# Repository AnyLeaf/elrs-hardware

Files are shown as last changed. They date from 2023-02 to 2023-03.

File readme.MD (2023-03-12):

# AnyLeaf ELRS 2.4Ghz diversity Rx hardware

This repo contains published hardware information for the AnyLeaf ELRS receivers.
It contains schematics, KiCad schematic and PCB layout files, and production files
(Gerbers, drill files, bill of materials (BOM), and pick+place files). If you have any questions
or concerns, please post a Github issue here, or contact us at [anyleaf@anyleaf.org](mailto:anyleaf@anyleaf.org).

## This repo contains 2 designs:
- Single radio (SX1280), with ESP8285 MCU, and SkyWorks SE2431 LNA/PA/antenna mux.
- Dual radio (SX1280), with ESP32-PICO-V3 MCU, and SkyWorks RFX2401C LNA/PAs.

Images of the schematics are provided as PNG files in the main repo; this is the easiest
way to view the schematics.

To view details, including PCB layouts, open the schematic and/or PCB files in 
[KiCad](https://www.kicad.org/).

For info on specific parts chosen, including part numbers at Digikey and LCSC, open
the schematic files in KiCad, and examine part properties.

All parts are on the same side of the PCB. Resistors and capacitors are *0402* size.

## [ExpressLRS home page](https://www.expresslrs.org/3.0/)

## [ExpressLRS hardware repo](https://github.com/ExpressLRS/ExpressLRS-Hardware)

## [AnyLeaf single-radio 2.4Ghz receiver](https://www.anyleaf.org/elrs-rx)

## [AnyLeaf dual-radio 2.4Ghz receiver](https://www.anyleaf.org/elrs-rx-dualradio)

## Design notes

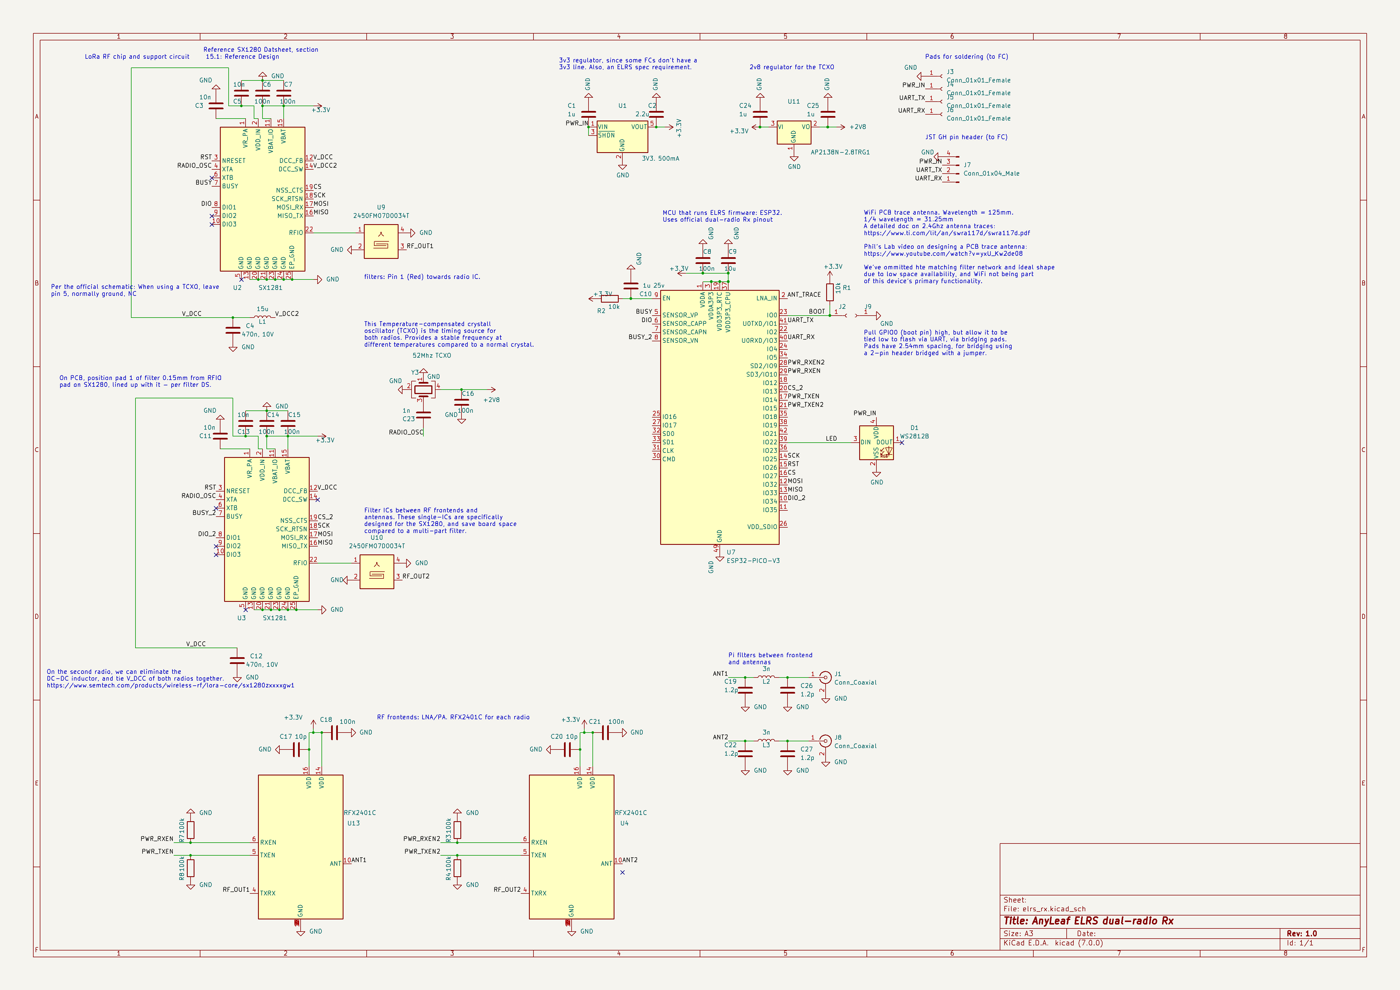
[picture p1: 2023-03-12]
dual radio 2.4Ghz schematic.png

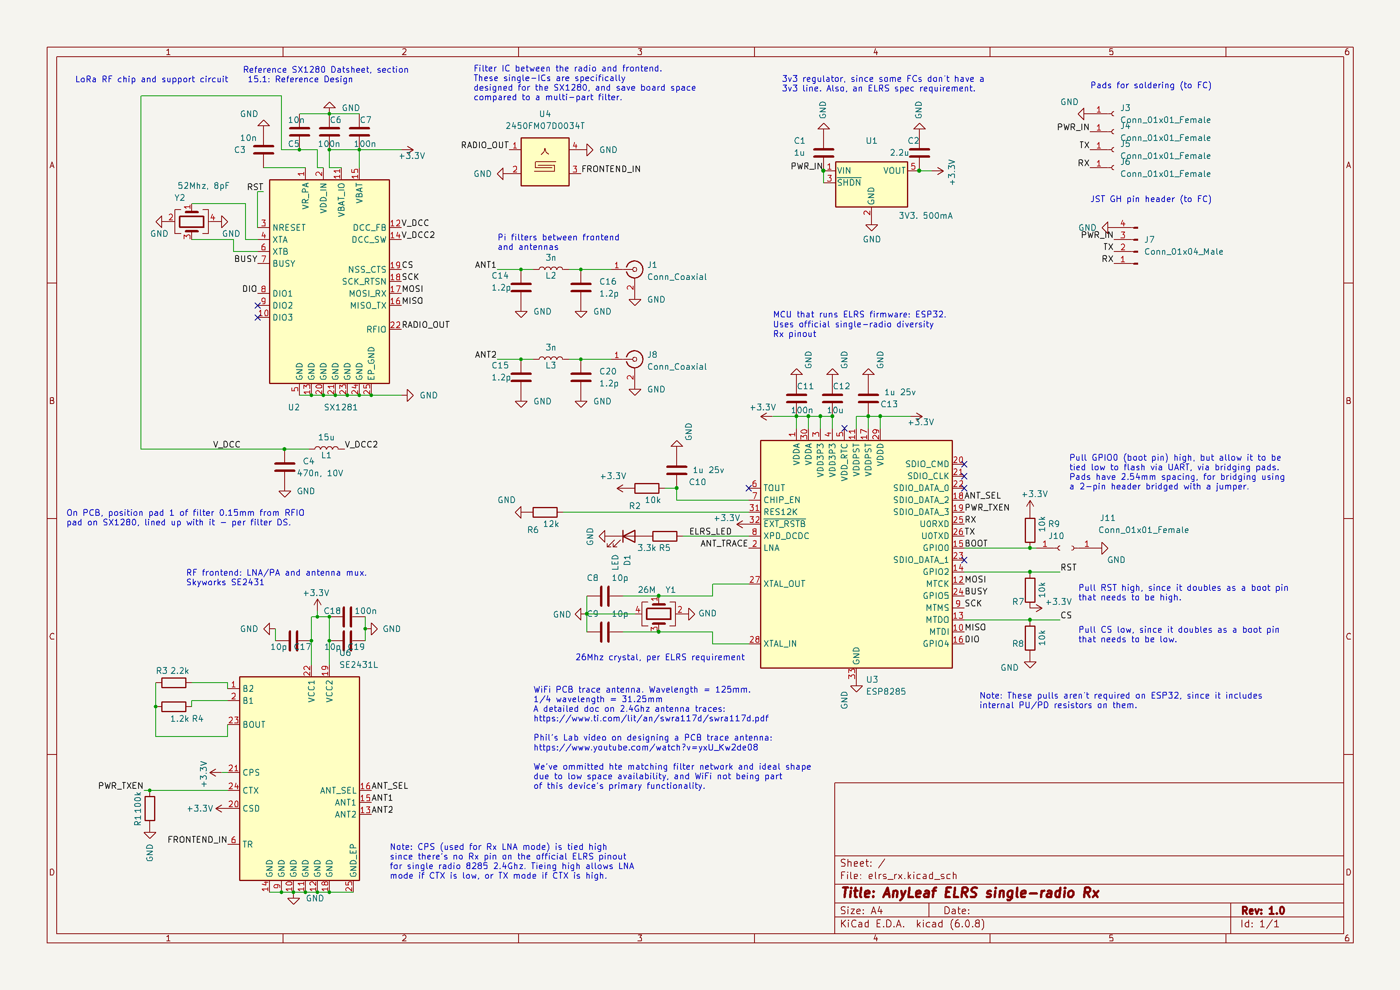
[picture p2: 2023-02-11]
single radio 2.4Ghz schematic.png

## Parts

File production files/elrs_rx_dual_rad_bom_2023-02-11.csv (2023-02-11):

Comment | Designator | Footprint | LCSC
1u | C1,C24,C25 | Capacitor_SMD:C_0402_1005Metric | C52923
1u 25v | C10 | Capacitor_SMD:C_0402_1005Metric | C52923
10p | C17,C20 | Capacitor_SMD:C_0402_1005Metric | C32949
1.2p | C19,C22,C26,C27 | Capacitor_SMD:C_0402_1005Metric | C327292
2.2u | C2 | Capacitor_SMD:C_0402_1005Metric | C12530
1n | C23 | Capacitor_SMD:C_0402_1005Metric | C1523
10n | C3,C5,C11,C13 | Capacitor_SMD:C_0402_1005Metric | C15195
470n, 10V | C4,C12 | Capacitor_SMD:C_0402_1005Metric | C47339
100n | C6,C7,C8,C14,C15,C16,C18,C21 | Capacitor_SMD:C_0402_1005Metric | C1525
10u | C9 | Capacitor_SMD:C_0402_1005Metric | C15525
WS2812B | D1 | LED_SMD:LED-APA102-2020 | C965555
Conn_Coaxial | J1,J8 | Connector_Coaxial:U.FL_Hirose_U.FL-R-SMT-1_Vertical | C88374
Conn_01x01_Female | J3,J4,J5,J6 | TestPoint:TestPoint_Pad_2.5x2.5mm
Conn_01x04_Male | J7 | Connector_JST:JST_GH_SM04B-GHS-TB_1x04-1MP_P1.25mm_Horizontal | C189895
15u | L1 | Inductor_SMD:L_0805_2012Metric | C486333
3n | L2,L3 | Inductor_SMD:L_0402_1005Metric | C269824
10k | R1,R2 | Resistor_SMD:R_0402_1005Metric | C25744
100k | R3,R4,R7,R8 | Resistor_SMD:R_0402_1005Metric | C25741
3V3. 500mA | U1 | Package_TO_SOT_SMD:TSOT-23-5 | C587158
AP2138N-2.8TRG1 | U11 | Package_TO_SOT_SMD:SOT-23 | C176956
AT2401C | U12,U13 | Package_DFN_QFN:QFN-16-1EP_3x3mm_P0.5mm_EP1.7x1.7mm | C783588
SX1281 | U2,U3 | Package_DFN_QFN:QFN-24-1EP_4x4mm_P0.5mm_EP2.6x2.6mm | C125969
ESP32-PICO-V3 | U7 | Package_DFN_QFN:QFN-48-1EP_7x7mm_P0.5mm_EP5.3x5.3mm | C967022
2450FM07D0034T | U9,U10 | Anyleaf_Shared:2450FM07D0034
52Mhz TCXO | Y3 | Crystal:Crystal_SMD_2016-4Pin_2.0x1.6mm

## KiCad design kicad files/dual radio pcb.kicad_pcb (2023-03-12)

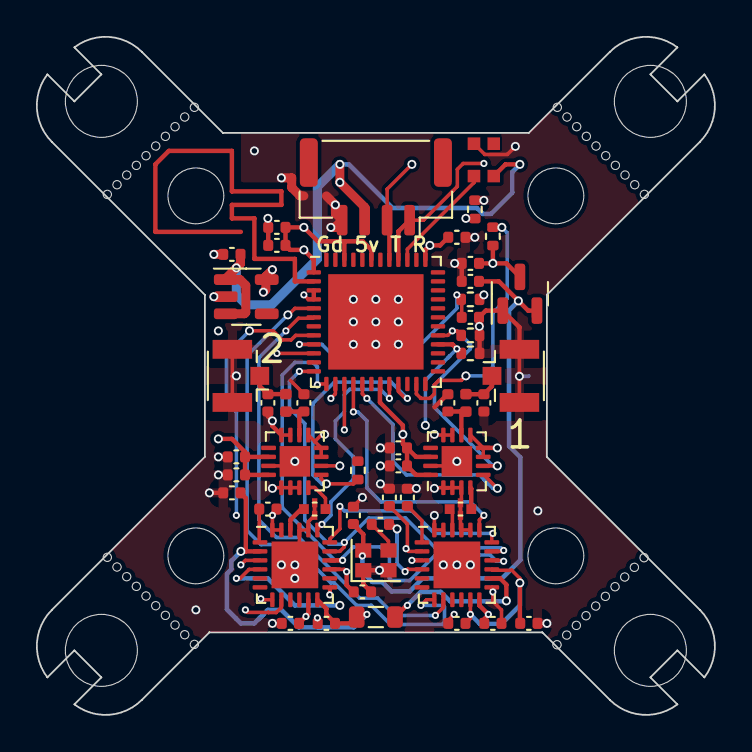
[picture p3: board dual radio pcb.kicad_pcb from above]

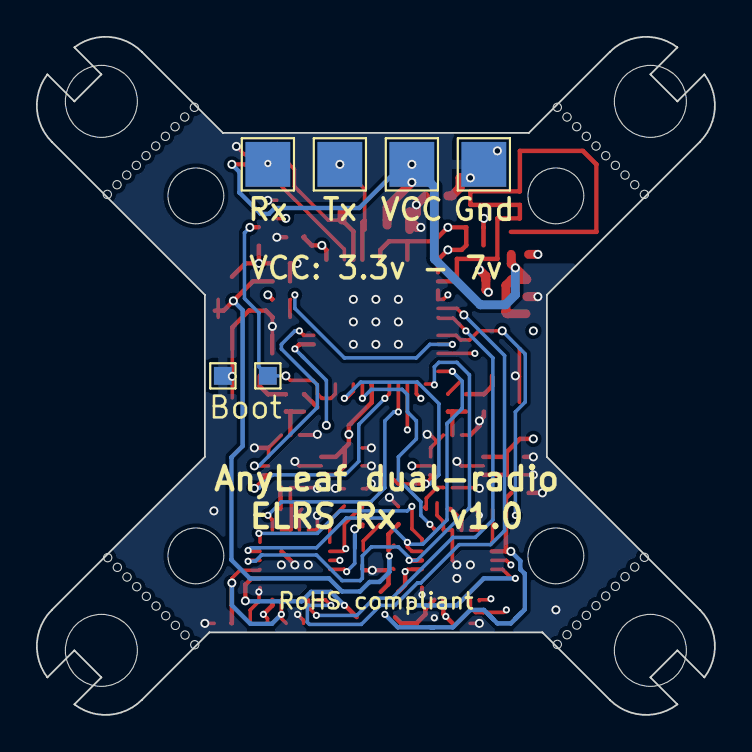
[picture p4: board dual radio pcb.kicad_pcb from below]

Board: 4 copper layers, 37.7 x 37.7 mm, 68 parts (6 on the bottom side), 37 nets.

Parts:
C1, C24, C25: 1u; C_0402_1005Metric
C2: 2.2u; C_0402_1005Metric
C3, C5, C11, C13: 10n; C_0402_1005Metric
C4, C12: 470n, 10V; C_0402_1005Metric
C6, C7, C8, C14, C15, C16, C18, C21: 100n; C_0402_1005Metric
C9: 10u; C_0402_1005Metric
C10: 1u 25v; C_0402_1005Metric
C17, C20: 10p; C_0402_1005Metric
C19, C22, C26, C27: 1.2p; C_0402_1005Metric
C23: 1n; C_0402_1005Metric
D1: WS2812B; LED-APA102-2020
H1, H2, H3, H4, H7, H8, H9, H10: MountingHole; MountingHole_3.2mm_M3
H5, H6, H11, H12: MountingHole_Pad; Mouse bites_7mm
J1, J8: Conn_Coaxial; U.FL_Hirose_U.FL-R-SMT-1_Vertical
J2, J9: Conn_01x01_Female; TestPoint_Pad_1.0x1.0mm
J3, J4, J5, J6: Conn_01x01_Female; TestPoint_Pad_2.5x2.5mm
J7: Conn_01x04_Male; JST_GH_SM04B-GHS-TB_1x04-1MP_P1.25mm_Horizontal
L1: 15u; L_0805_2012Metric
L2, L3: 3n; L_0402_1005Metric
R1, R2: 10k; R_0402_1005Metric
R3, R4, R7, R8: 100k; R_0402_1005Metric
U1: 3V3. 500mA; TSOT-23-5
U2, U3: SX1281; QFN-24-1EP_4x4mm_P0.5mm_EP2.6x2.6mm
U4, U13: RFX2401C; QFN-16-1EP_3x3mm_P0.5mm_EP1.7x1.7mm
U7: ESP32-PICO-V3; QFN-48-1EP_7x7mm_P0.5mm_EP5.3x5.3mm
U9, U10: 2450FM07D0034T; 2450FM07D0034
U11: AP2138N-2.8TRG1; SOT-23
Y3: 52Mhz TCXO; Crystal_SMD_2016-4Pin_2.0x1.6mm

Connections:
+2V8: C16.1, C25.2, U11.2 (VO), Y3.4
+3V3: C2.2, C6.2, C7.2, C8.2, C9.2, C14.2, C15.2, C17.2, C18.1, C20.2, C21.1, C24.2, R1.1, R2.2, U1.5 (VOUT), U2.11 (VBAT_IO), U2.15 (VBAT), U3.11 (VBAT_IO), U3.15 (VBAT), U4.14 (VDD), U4.16 (VDD), U7.1 (VDDA), U7.3 (VDDA3P3), U7.4 (VDDA3P3), U7.19 (VDD3P3_RTC), U7.37 (VDD3P3_CPU), U7.43 (VDDA), U7.46 (VDDA), U11.3 (VI), U13.14 (VDD), U13.16 (VDD)
/ANT1: C19.1, L2.1, U13.10 (ANT)
/ANT2: C22.1, L3.1, U4.10 (ANT)
/BOOT: J2.1, R1.2, U7.23 (IO0)
/BUSY: U2.7 (BUSY), U7.5 (SENSOR_VP)
/BUSY_2: U3.7 (BUSY), U7.8 (SENSOR_VN)
/CS: U2.19 (NSS_CTS), U7.16 (IO27)
/CS_2: U3.19 (NSS_CTS), U7.20 (IO13)
/DIO: U2.8 (DIO1), U7.6 (SENSOR_CAPP)
/DIO_2: U3.8 (DIO1), U7.10 (IO34)
/LED: D1.3 (DIN), U7.39 (IO22)
/MISO: U2.16 (MISO_TX), U3.16 (MISO_TX), U7.13 (IO33)
/MOSI: U2.17 (MOSI_RX), U3.17 (MOSI_RX), U7.12 (IO32)
/PWR_IN: C1.2, D1.4 (VDD), J4.1, J7.3, U1.1 (VIN), U1.3 (~SHDN)
/PWR_RXEN: R7.2, U7.29 (SD3/IO10), U13.6 (RXEN)
/PWR_RXEN2: R3.2, U4.6 (RXEN), U7.28 (SD2/IO9)
/PWR_TXEN: R8.1, U7.17 (IO14), U13.5 (TXEN)
/PWR_TXEN2: R4.1, U4.5 (TXEN), U7.21 (IO15)
/RADIO_OSC: C23.2, U2.4 (XTA), U3.4 (XTA)
/RF_OUT1: U9.3, U13.4 (TXRX)
/RF_OUT2: U4.4 (TXRX), U10.3
/RST: U2.3 (NRESET), U3.3 (NRESET), U7.15 (IO26)
/SCK: U2.18 (SCK_RTSN), U3.18 (SCK_RTSN), U7.14 (IO25)
/UART_RX: J6.1, J7.1, U7.40 (U0RXD/IO3)
/UART_TX: J5.1, J7.2, U7.41 (U0TXD/IO1)
/V_DCC: C4.1, C5.2, C12.1, C13.2, L1.1, U2.2 (VDD_IN), U2.12 (DCC_FB), U3.2 (VDD_IN), U3.12 (DCC_FB)
/V_DCC2: L1.2, U2.14 (DCC_SW)
GND: C1.1, C2.1, C3.1, C4.2, C5.1, C6.1, C7.1, C8.1, C9.1, C10.2, C11.1, C12.2, C13.1, C14.1, C15.1, C16.2, C17.1, C18.2, C19.2, C20.1, C21.2, C22.2, C24.1, C25.1, C26.2, C27.2, D1.2 (VSS), J1.2 (Ext), J3.1, J7.4, J8.2 (Ext), J9.1, R3.1, R4.2, R7.1, R8.2, U1.2 (GND), U2.13 (GND), U2.20 (GND), U2.21 (GND), U2.23 (GND), U2.24 (GND), U2.25 (EP_GND), U3.13 (GND), U3.20 (GND), U3.21 (GND), U3.23 (GND), U3.24 (GND), U3.25 (EP_GND), U4.1 (GND), U4.2 (GND), U4.3 (GND), U4.7 (GND), U4.8 (GND), U4.9 (GND), U4.11 (GND), U4.12 (GND), U4.15 (GND), U4.17 (GND), U7.49 (GND), U9.2, U9.4, U10.2, U10.4, U11.1 (GND), U13.1 (GND), U13.2 (GND), U13.3 (GND), U13.7 (GND), U13.8 (GND), U13.9 (GND), U13.11 (GND), U13.12 (GND), U13.15 (GND), U13.17 (GND), Y3.1, Y3.2
unnamed: C23.1, Y3.3
unnamed: C26.1, J1.1 (In), L2.2
unnamed: C27.1, J8.1 (In), L3.2
unnamed: U2.22 (RFIO), U9.1
unnamed: C3.2, U2.1 (VR_PA)
unnamed: U3.22 (RFIO), U10.1
unnamed: C11.2, U3.1 (VR_PA)
unnamed: C10.1, R2.1, U7.9 (EN)

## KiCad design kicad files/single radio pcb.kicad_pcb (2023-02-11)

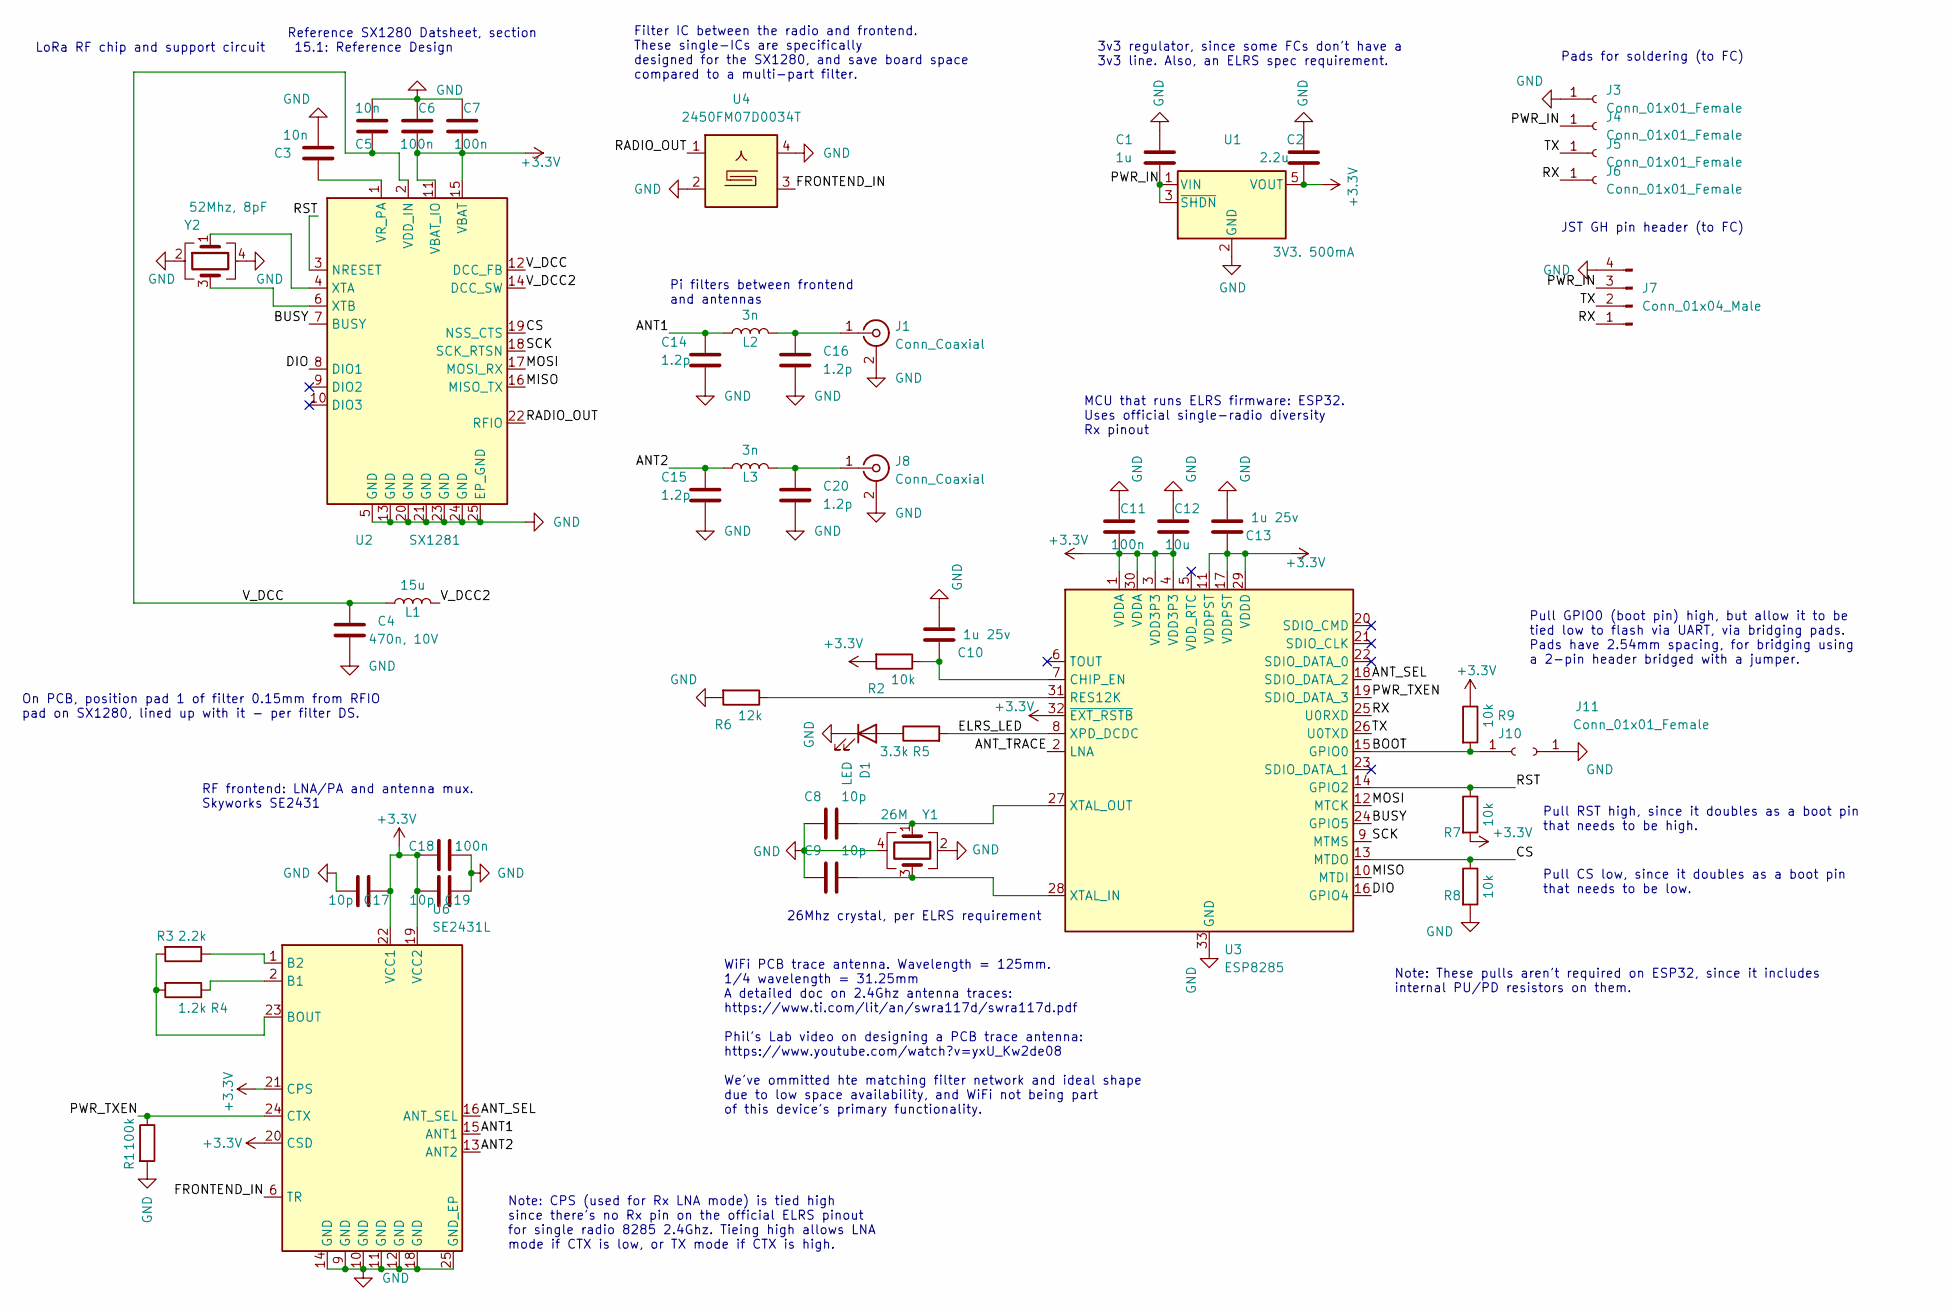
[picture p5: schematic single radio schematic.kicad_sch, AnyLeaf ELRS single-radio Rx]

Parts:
C1: 1u; C_0402_1005Metric; LCSC C52923
C2: 2.2u; C_0402_1005Metric; LCSC C12530
C3, C5: 10n; C_0402_1005Metric; LCSC C15195
C4: 470n, 10V; C_0402_1005Metric; LCSC C47339
C6, C7, C11, C18: 100n; C_0402_1005Metric; LCSC C1525
C8, C9, C17, C19: 10p; C_0402_1005Metric; LCSC C32949
C10, C13: 1u 25v; C_0402_1005Metric; LCSC C52923
C12: 10u; C_0402_1005Metric; LCSC C15525
C14, C15, C16, C20: 1.2p; C_0402_1005Metric; LCSC C327292
D1: LED; LED_0603_1608Metric; LCSC C2286
J1, J8: Conn_Coaxial; U.FL_Hirose_U.FL-R-SMT-1_Vertical; Part Hirose U.FL-R-SMT-1(80); LCSC C88374
J3, J4, J5, J6: Conn_01x01_Female; TestPoint_Pad_2.5x2.5mm
J7: Conn_01x04_Male; JST_GH_SM04B-GHS-TB_1x04-1MP_P1.25mm_Horizontal; LCSC C189895
J10, J11: Conn_01x01_Female; TestPoint_Pad_1.0x1.0mm
L1: 15u; L_0805_2012Metric; LCSC C486333
L2, L3: 3n; L_0402_1005Metric; LCSC C269824
R1: 100k; R_0402_1005Metric; LCSC C25741
R2, R7, R8, R9: 10k; R_0402_1005Metric; LCSC C25744
R3: 2.2k; R_0402_1005Metric; LCSC C25879
R4: 1.2k; R_0402_1005Metric; LCSC C25862
R5: 3.3k; R_0402_1005Metric; LCSC C25890
R6: 12k; R_0402_1005Metric; LCSC C25752
U1: 3V3. 500mA; TSOT-23-5; Part TPRT9013-33GB; LCSC C587158
U2: SX1281; QFN-24-1EP_4x4mm_P0.5mm_EP2.6x2.6mm; Digikey SX1281IMLTRTTR-ND
U3: ESP8285; QFN-32-1EP_5x5mm_P0.5mm_EP3.45x3.45mm; LCSC C967019
U4: 2450FM07D0034T; 2450FM07D0034; Mouser 609-2450FM07D0034T
U6: SE2431L; QFN-24-1EP_3x4mm_P0.4mm_EP1.65x2.65mm; Digikey 863-1347-2-ND
Y1: 26M; Crystal_SMD_2016-4Pin_2.0x1.6mm; LCSC C843259
Y2: 52Mhz, 8pF; Crystal_SMD_2016-4Pin_2.0x1.6mm; LCSC C781783

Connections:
+3V3: C2.2, C6.2, C7.2, C11.2, C12.2, C13.1, C17.2, C18.1, C19.1, R2.2, R7.2, R9.1, U1.5 (VOUT), U2.11 (VBAT_IO), U2.15 (VBAT), U3.1 (VDDA), U3.3 (VDD3P3), U3.4 (VDD3P3), U3.11 (VDDPST), U3.17 (VDDPST), U3.29 (VDDD), U3.30 (VDDA), U3.32 (~EXT_RSTB), U6.19 (VCC2), U6.20 (CSD), U6.21 (CPS), U6.22 (VCC1)
/ANT1: C14.1, L2.1, U6.15 (ANT1)
/ANT2: C15.1, L3.1, U6.13 (ANT2)
/ANT_SEL: U3.18 (SDIO_DATA_2), U6.16 (ANT_SEL)
/ANT_TRACE: U3.2 (LNA)
/BOOT: J10.1, R9.2, U3.15 (GPIO0)
/BUSY: U2.7 (BUSY), U3.24 (GPIO5)
/CS: R8.1, U2.19 (NSS_CTS), U3.13 (MTDO)
/DIO: U2.8 (DIO1), U3.16 (GPIO4)
/ELRS_LED: R5.2, U3.8 (XPD_DCDC)
/FRONTEND_IN: U4.3, U6.6 (TR)
/MISO: U2.16 (MISO_TX), U3.10 (MTDI)
/MOSI: U2.17 (MOSI_RX), U3.12 (MTCK)
/PWR_IN: C1.2, J4.1, J7.3, U1.1 (VIN), U1.3 (~SHDN)
/PWR_TXEN: R1.1, U3.19 (SDIO_DATA_3), U6.24 (CTX)
/RADIO_OUT: U2.22 (RFIO), U4.1
/RST: R7.1, U2.3 (NRESET), U3.14 (GPIO2)
/RX: J6.1, J7.1, U3.25 (U0RXD)
/SCK: U2.18 (SCK_RTSN), U3.9 (MTMS)
/TX: J5.1, J7.2, U3.26 (U0TXD)
/V_DCC: C4.1, C5.2, L1.1, U2.2 (VDD_IN), U2.12 (DCC_FB)
/V_DCC2: L1.2, U2.14 (DCC_SW)
GND: C1.1, C2.1, C3.1, C4.2, C5.1, C6.1, C7.1, C8.1, C9.1, C10.2, C11.1, C12.1, C13.2, C14.2, C15.2, C16.2, C17.1, C18.2, C19.2, C20.2, D1.1 (K), J1.2 (Ext), J3.1, J7.4, J8.2 (Ext), J11.1, R1.2, R6.2, R8.2, U1.2 (GND), U2.5 (GND), U2.13 (GND), U2.20 (GND), U2.21 (GND), U2.23 (GND), U2.24 (GND), U2.25 (EP_GND), U3.33 (GND), U4.2, U4.4, U4.5, U6.9 (GND), U6.10 (GND), U6.11 (GND), U6.12 (GND), U6.14 (GND), U6.18 (GND), U6.25 (GND_EP), Y1.2, Y1.4, Y2.2, Y2.4
unnamed: C3.2, U2.1 (VR_PA)
unnamed: C8.2, U3.27 (XTAL_OUT), Y1.1
unnamed: C9.2, U3.28 (XTAL_IN), Y1.3
unnamed: C10.1, R2.1, U3.7 (CHIP_EN)
unnamed: C16.1, J1.1 (In), L2.2
unnamed: C20.1, J8.1 (In), L3.2
unnamed: D1.2 (A), R5.1
unnamed: R3.1, U6.1 (B2)
unnamed: R3.2, R4.2, U6.23 (BOUT)
unnamed: R4.1, U6.2 (B1)
unnamed: R6.1, U3.31 (RES12K)
unnamed: U2.4 (XTA), Y2.1
unnamed: U2.6 (XTB), Y2.3

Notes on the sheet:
26Mhz crystal, per ELRS requirement
MCU that runs ELRS firmware: ESP32. Uses official single-radio diversity Rx pinout
JST GH pin header (to FC)
Note: These pulls aren't required on ESP32, since it includes internal PU/PD resistors on them.
Pi filters between frontend and antennas
Pads for soldering (to FC)
Note: CPS (used for Rx LNA mode) is tied high since there's no Rx pin on the official ELRS pinout for single radio 8285 2.4Ghz. Tieing high allows LNA mode if CTX is low, or TX mode if CTX is high.
3v3 regulator, since some FCs don't have a 3v3 line. Also, an ELRS spec requirement.
WiFi PCB trace antenna. Wavelength = 125mm. 1/4 wavelength = 31.25mm A detailed doc on 2.4Ghz antenna traces: https://www.ti.com/lit/an/swra117d/swra117d.pdf Phil's Lab video on designing a PCB trace antenna: https://www.youtube.com/watch?v=yxU_Kw2de08 We've ommitted hte matching filter network and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
Pull CS low, since it doubles as a boot pin that needs to be low.
Reference SX1280 Datsheet, section 15.1: Reference Design
RF frontend: LNA/PA and antenna mux. Skyworks SE2431
Pull GPIO0 (boot pin) high, but allow it to be tied low to flash via UART, via bridging pads. Pads have 2.54mm spacing, for bridging using a 2-pin header bridged with a jumper.
On PCB, position pad 1 of filter 0.15mm from RFIO pad on SX1280, lined up with it - per filter DS.
Pull RST high, since it doubles as a boot pin that needs to be high.
LoRa RF chip and support circuit
Filter IC between the radio and frontend. These single-ICs are specifically designed for the SX1280, and save board space compared to a multi-part filter.

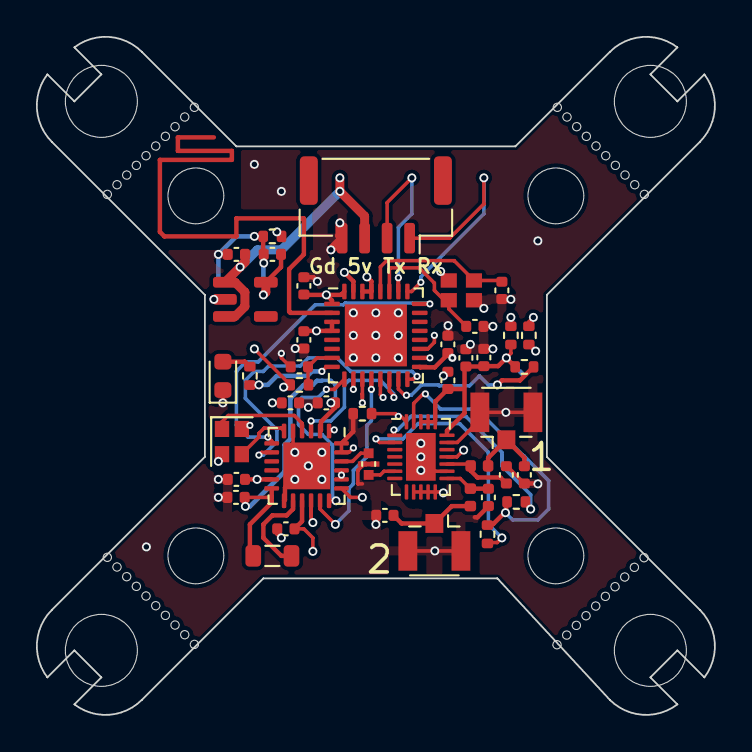
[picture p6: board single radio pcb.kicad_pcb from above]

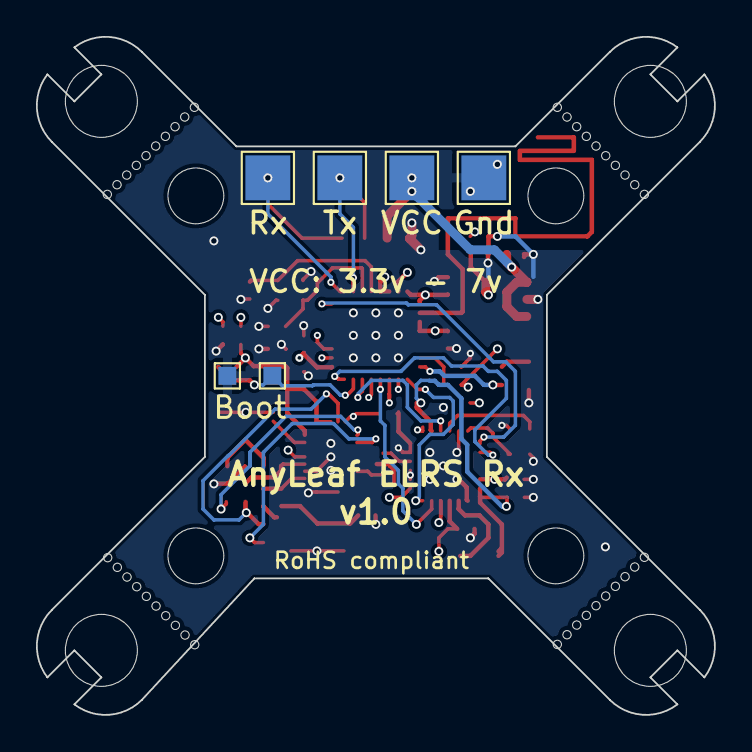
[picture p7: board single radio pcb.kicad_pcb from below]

Board: 4 copper layers, 37.7 x 37.7 mm, 61 parts (6 on the bottom side), 35 nets.

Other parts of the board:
H1, H2, H3, H4, H7, H8, H9, H10: MountingHole; MountingHole_3.2mm_M3
H5, H6, H11, H12: MountingHole_Pad; Mouse bites_7mm

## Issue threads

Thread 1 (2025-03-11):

How to Upload Code from STM32CubeIDE to a DIY Flight Controller with an On-Board 2.4GHz Nano Receiver

LongDo1902, 2025-03-11:
Hello everyone,

Thanks for the schematic! I just followed yours to design a flight controller with an on-board nano receiver. Once I have the actual flight controller, I will write all the code for it using STM32CubeIDE. My current challenge is figuring out how to upload code from STM32CubeIDE to the on-board 2.4GHz receiver. Can anyone help?

Thank you very much!

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

David-OConnor, 2025-03-12:
If I understand this, that's not feasible: The radio receiver uses ESP32, as your diagram shows; you would not use Cube for that, and would likely flash over UART.

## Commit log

2023-01-14 folder rename
    [elrs_rx_dual_rad_2022-12-12_bom.csv, elrs_rx_single_rad_2023-01-14_bom.csv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]
2023-01-14 Troubleshooting disapeared gerbers
2023-01-14 Updated dual radio to eliminate second rad's inductor
    [dual radio pcb.kicad_pcb, dual radio schematic.kicad_sch]
2023-02-11 Updates including dif filter by antenna, better WiFi PCB antenna, and single inductor
    [dual radio pcb.kicad_pcb, dual radio schematic.kicad_sch, elrs_rx_dual_rad_bom_2023-02-11.csv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]
2023-03-12 Updated dual rad to use RFX2401C frontends
    [dual radio pcb.kicad_pcb, dual radio schematic.kicad_sch]
